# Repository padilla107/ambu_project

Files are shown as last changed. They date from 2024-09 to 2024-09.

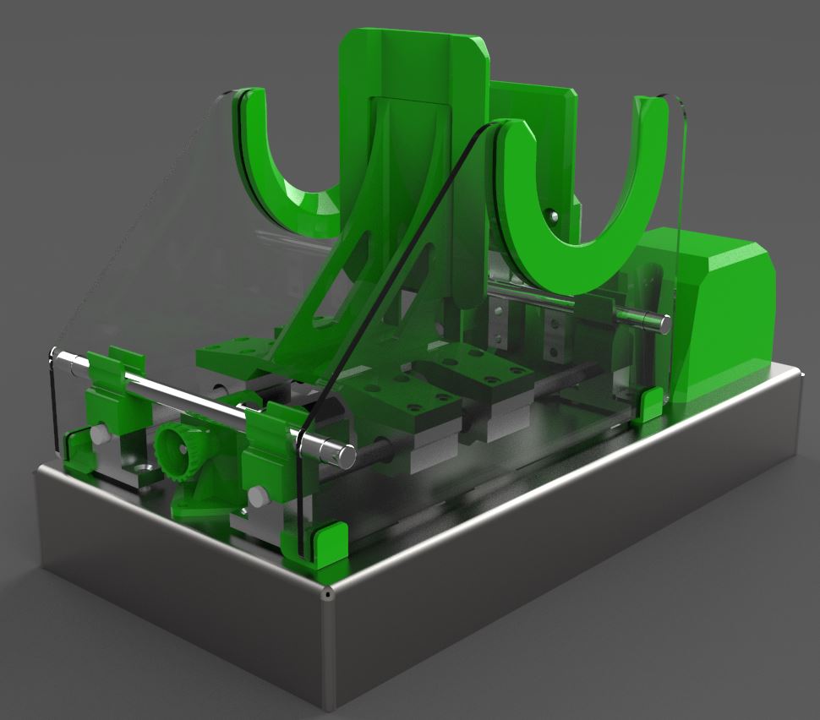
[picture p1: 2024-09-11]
Diseño/Proyección/011.JPG

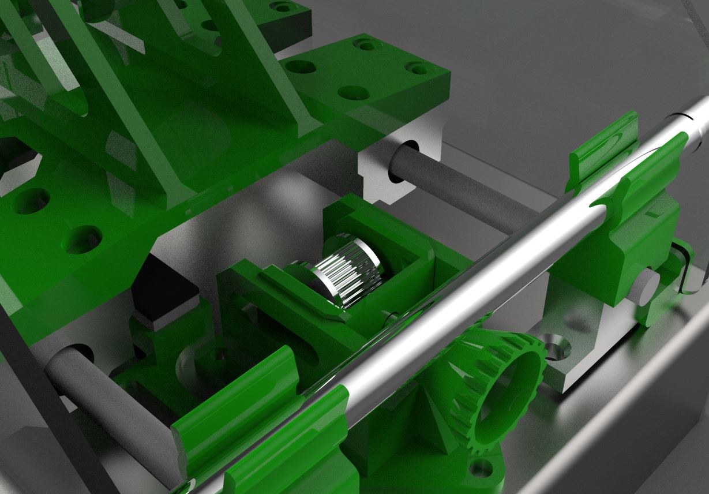
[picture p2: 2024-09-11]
Diseño/Proyección/012.JPG

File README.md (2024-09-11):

# Sistema de Apoyo para la Respiración No Invasivo

## Descripción

Este repositorio contiene los recursos completos para la construcción de un sistema de apoyo respiratorio no invasivo, diseñado para enfrentar la carencia de equipamiento médico en situaciones de emergencia, como la pandemia de COVID-19. El proyecto incluye diseños en 3D, esquemas electrónicos y programación de microcontroladores, con un enfoque en la accesibilidad y el código abierto.

## Recursos Incluidos

- **Diseños 3D**: Archivos en formato STL y OBJ listos para impresión 3D, incluyendo la estructura y componentes mecánicos del sistema.
- **Circuito Esquemático**: Planos electrónicos detallados del dispositivo.
- **Archivos Gerber**: Recursos para la fabricación del PCB, listos para ser enviados a fabricantes de placas de circuito impreso.
- **Código de Programación**: Código fuente para el microcontrolador ESP32, incluyendo la configuración y funcionalidades del sistema.
- **Guía de Fabricación**: Paso a paso detallado para la construcción y montaje del dispositivo, desde la impresión de componentes hasta la programación final.
- **Tesis Completa**: Documento académico que respalda el proyecto, incluyendo la investigación, diseño y desarrollo del sistema.

## Objetivo

Crear una solución replicable y de bajo costo para la ventilación no invasiva, que pueda ser utilizada tanto en entornos hospitalarios como en el hogar.

## Tecnologías Utilizadas

- Microcontroladores ESP32
- Software Autodesk Inventor para diseño mecánico
- Impresoras 3D
- Circuitos PCB con archivos Gerber

## Contribuciones

Este proyecto está diseñado para ser accesible y mejorado por la comunidad. Cualquier contribución para optimizar el diseño, mejorar la programación o adaptar el sistema a nuevas necesidades es bienvenida.

---

# Non-Invasive Breathing Support System

## Description

This repository contains the complete resources for building a non-invasive respiratory support system, designed to address the lack of medical equipment in emergency situations, such as the COVID-19 pandemic. The project includes 3D designs, electronic schematics, and microcontroller programming, with a focus on accessibility and open source.

## Included Resources

- **3D designs**: Files in STL and OBJ format ready for 3D printing, including the structure and mechanical components of the system.
- **Schematic Circuit**: Detailed electronic drawings of the device.
- **Gerber Files**: Resources for PCB manufacturing, ready to be sent to printed circuit board manufacturers.
- **Programming Code**: Source code for the ESP32 microcontroller, including system configuration and functionalities.
- **Manufacturing Guide**: Detailed step by step for the construction and assembly of the device, from component printing to final programming.
- **Complete Thesis**: Academic document that supports the project, including research, system design, and development.

## Aim

Create a low-cost, replicable solution for non-invasive ventilation, that can be used both in hospital environments and at home.

## Technologies Used

- ESP32 Microcontrollers
- Autodesk Inventor software for mechanical design
- 3D printers
- PCB Circuits with Gerber Files

## Contributions

This project is designed to be accessible and enhanced by the community. Any contribution to optimize the design, improve programming, or adapt the system to new needs is welcome.

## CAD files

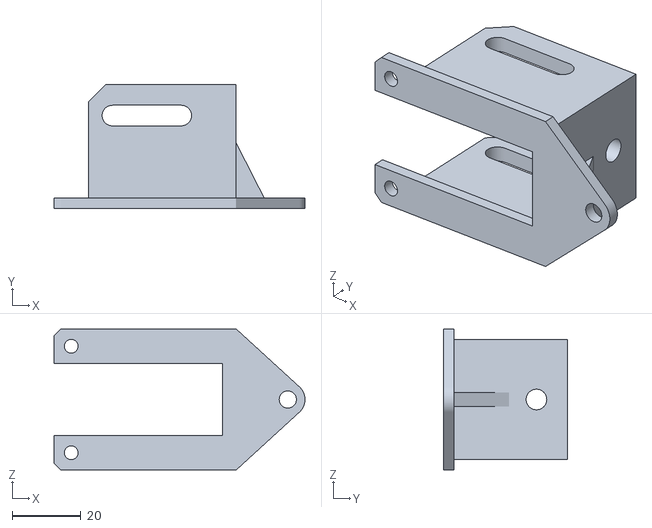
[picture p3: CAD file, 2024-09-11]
Diseño/Impresión 3D/base de tensor.stl
73.0 x 36.0 x 41.0

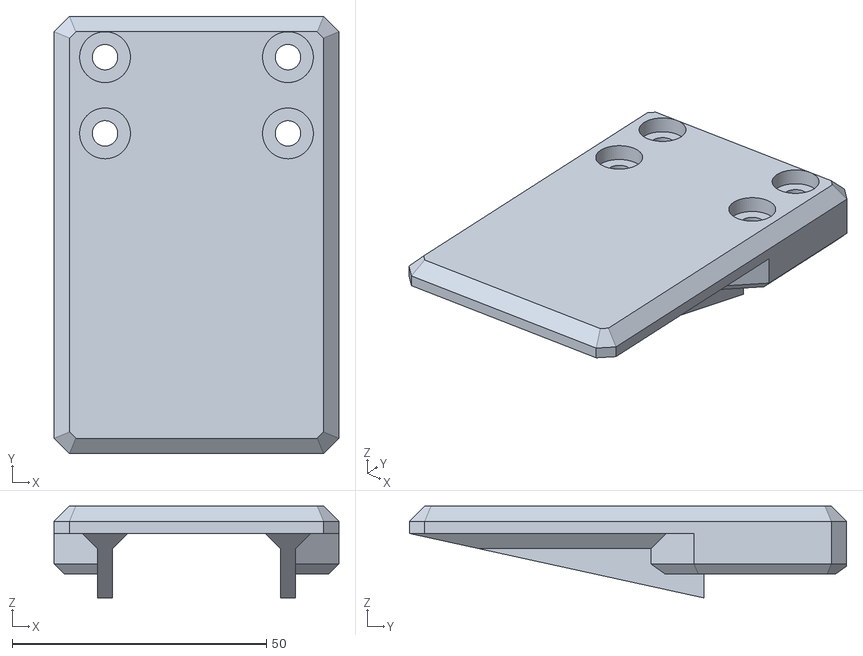
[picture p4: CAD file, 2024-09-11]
Diseño/Impresión 3D/Paleta de celda de carga.stl
56.0 x 86.0 x 18.1

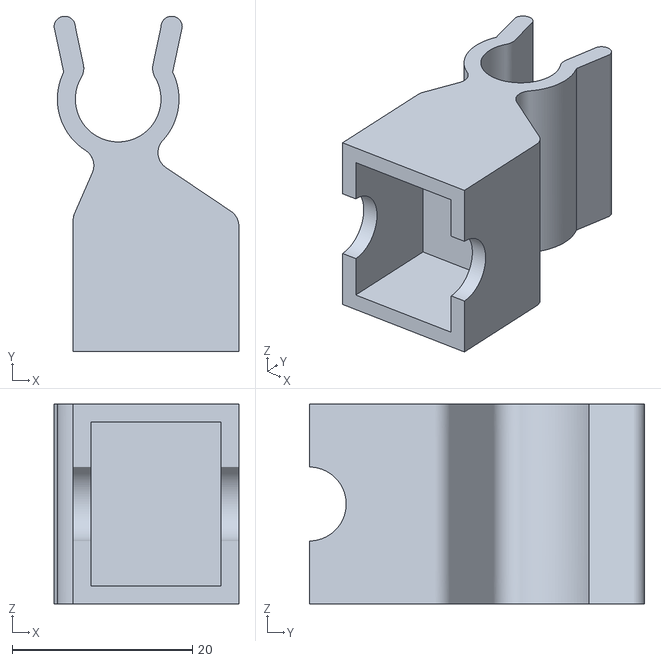
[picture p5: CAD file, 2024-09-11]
Diseño/Impresión 3D/Sujetador tornillo soporte mica delantero.stl
20.5 x 37.2 x 22.2

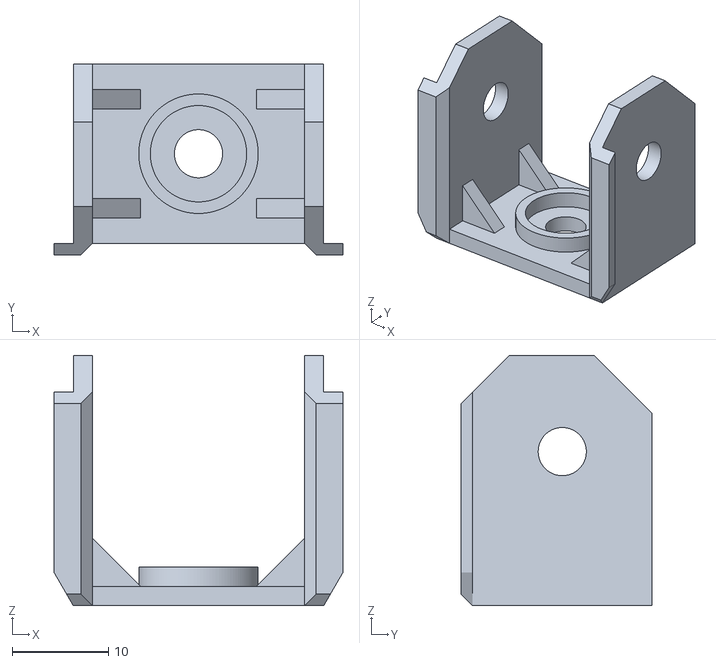
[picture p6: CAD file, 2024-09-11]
Diseño/Impresión 3D/deslizante de tensor.stl
30.0 x 19.8 x 26.0

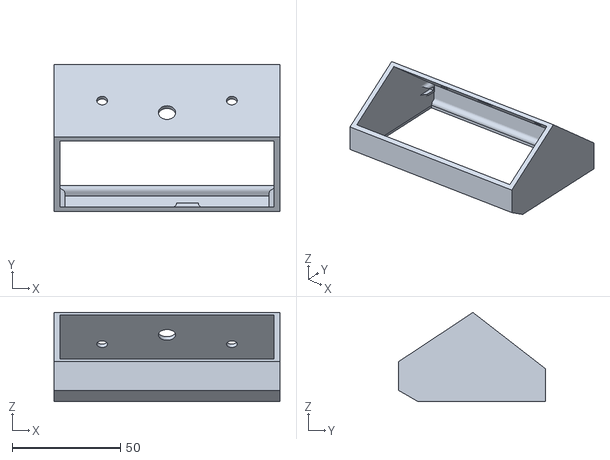
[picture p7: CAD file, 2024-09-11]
Diseño/Impresión 3D/Carcasa LCD.stl
104.5 x 68.0 x 41.2

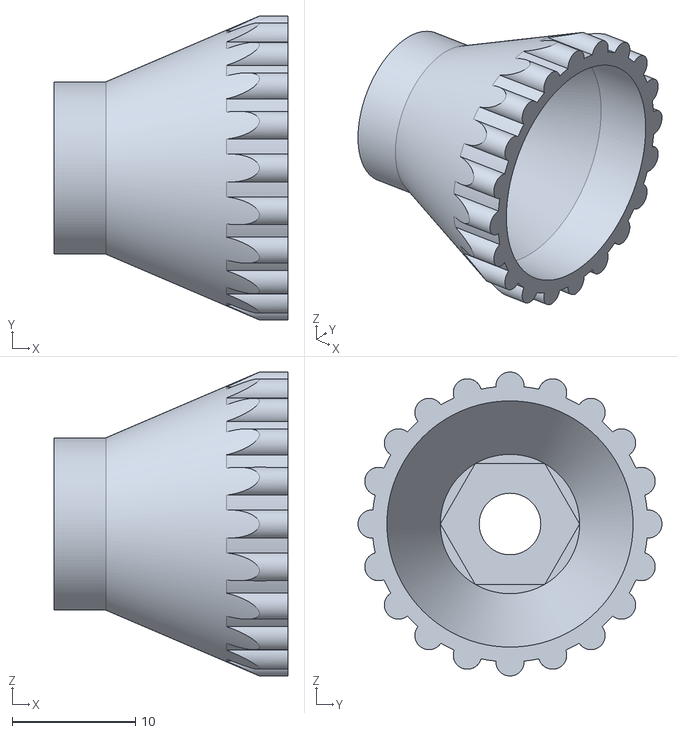
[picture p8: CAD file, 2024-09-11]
Diseño/Impresión 3D/perilla de tensor.stl
19.0 x 24.7 x 24.7

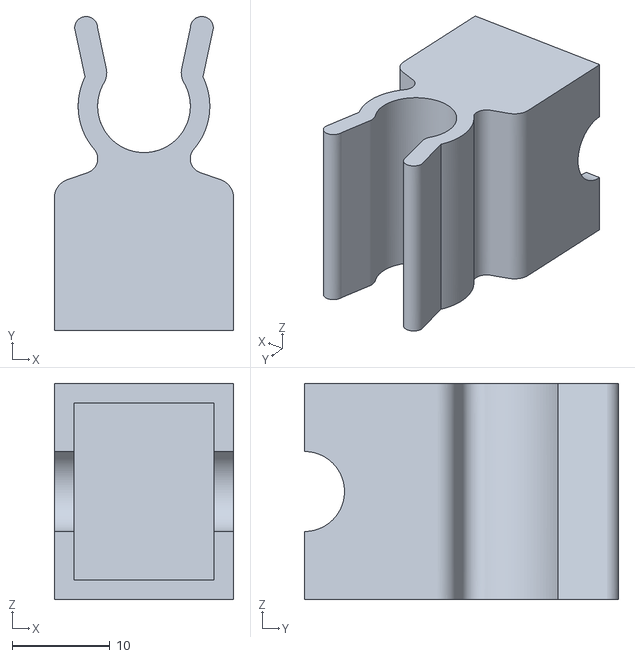
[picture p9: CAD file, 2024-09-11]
Diseño/Impresión 3D/Sujetador tornillo soporte mica trasero.stl
18.4 x 32.2 x 22.2

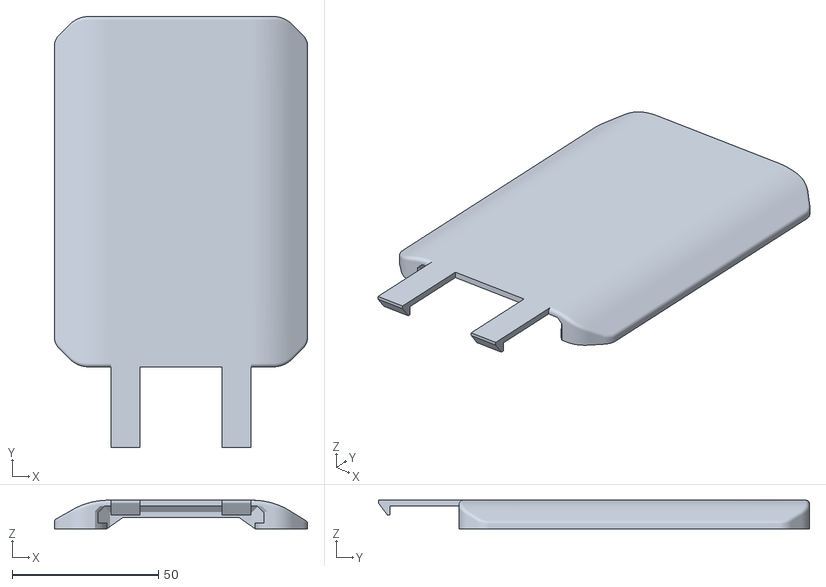
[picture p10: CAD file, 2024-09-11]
Diseño/Impresión 3D/camisa_paleta.stl
86.8 x 147.6 x 9.80

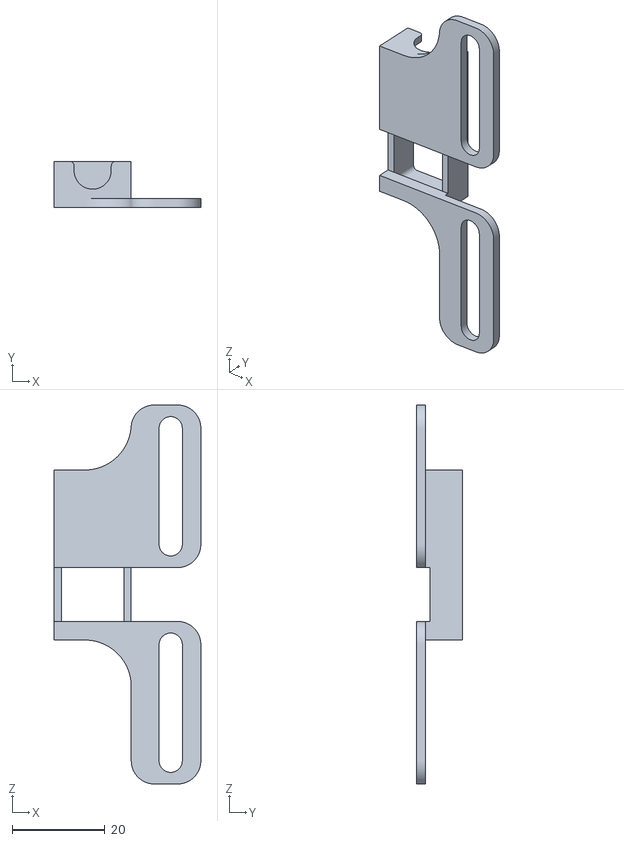
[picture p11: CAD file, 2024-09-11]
Diseño/Impresión 3D/Porta sensor magnetico.stl
31.6 x 10.0 x 81.6

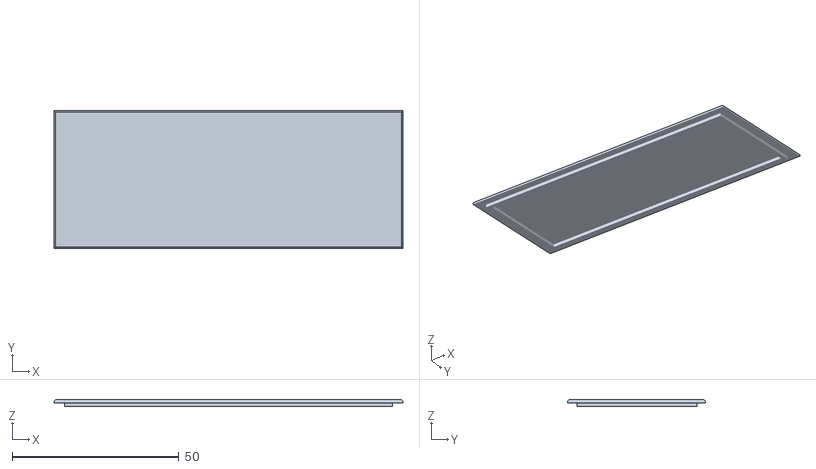
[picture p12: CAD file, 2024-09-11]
Diseño/Impresión 3D/Tapa de carcasa LCD.stl
104.5 x 41.3 x 2.00

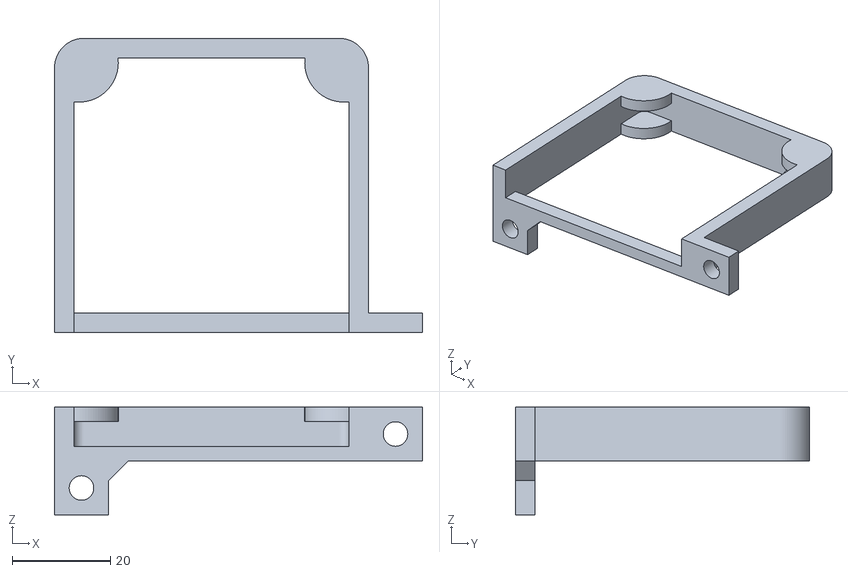
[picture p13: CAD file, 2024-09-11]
Diseño/Impresión 3D/Soporte delantero motor.stl
75.0 x 60.0 x 22.0

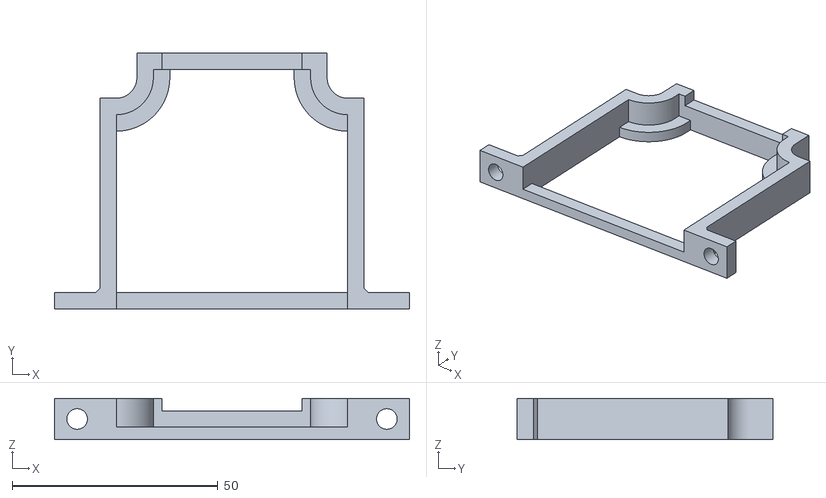
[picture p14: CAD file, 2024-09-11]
Diseño/Impresión 3D/Soporte trasero motor.stl
86.2 x 62.2 x 10.0

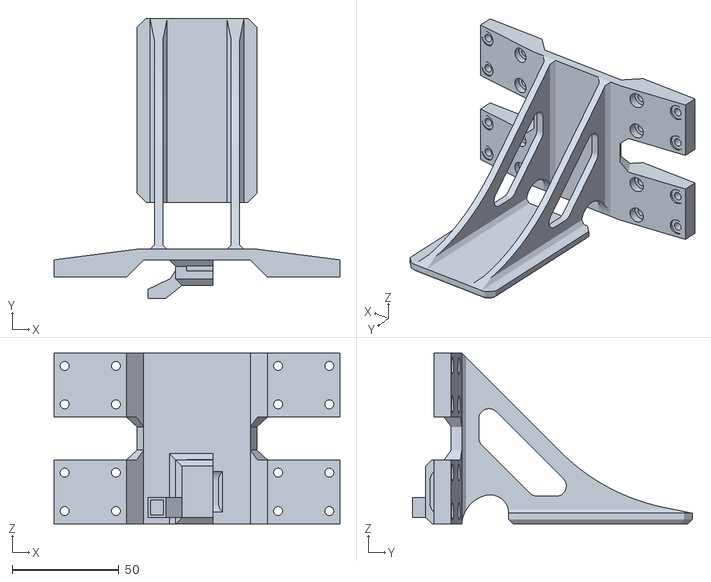
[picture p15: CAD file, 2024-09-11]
Diseño/Impresión 3D/Soporte central.stl
134.0 x 131.0 x 80.0

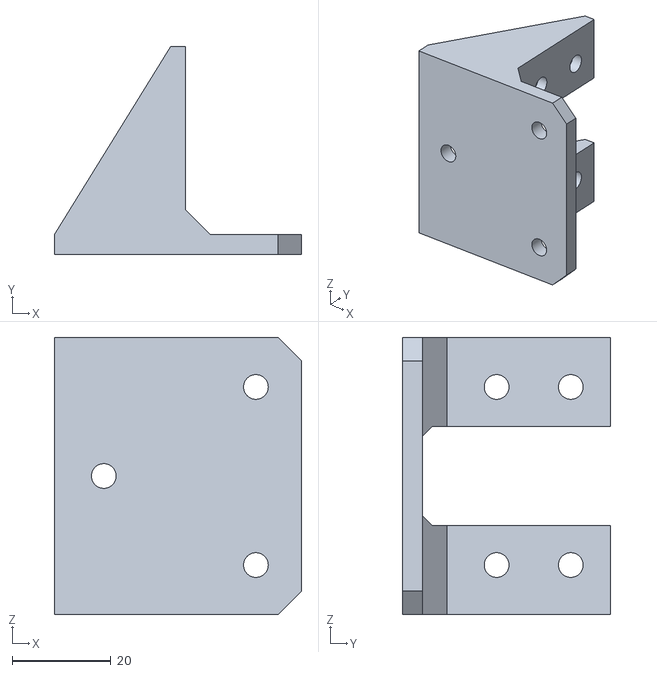
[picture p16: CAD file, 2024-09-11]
Diseño/Impresión 3D/Base de celda de carga.stl
50.0 x 42.0 x 56.0

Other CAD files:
Diseño/Impresión 3D/Sujetador mica derecho.stl
Diseño/Impresión 3D/Cover motor.stl
Diseño/Impresión 3D/Sujetador mica izquierdo.stl

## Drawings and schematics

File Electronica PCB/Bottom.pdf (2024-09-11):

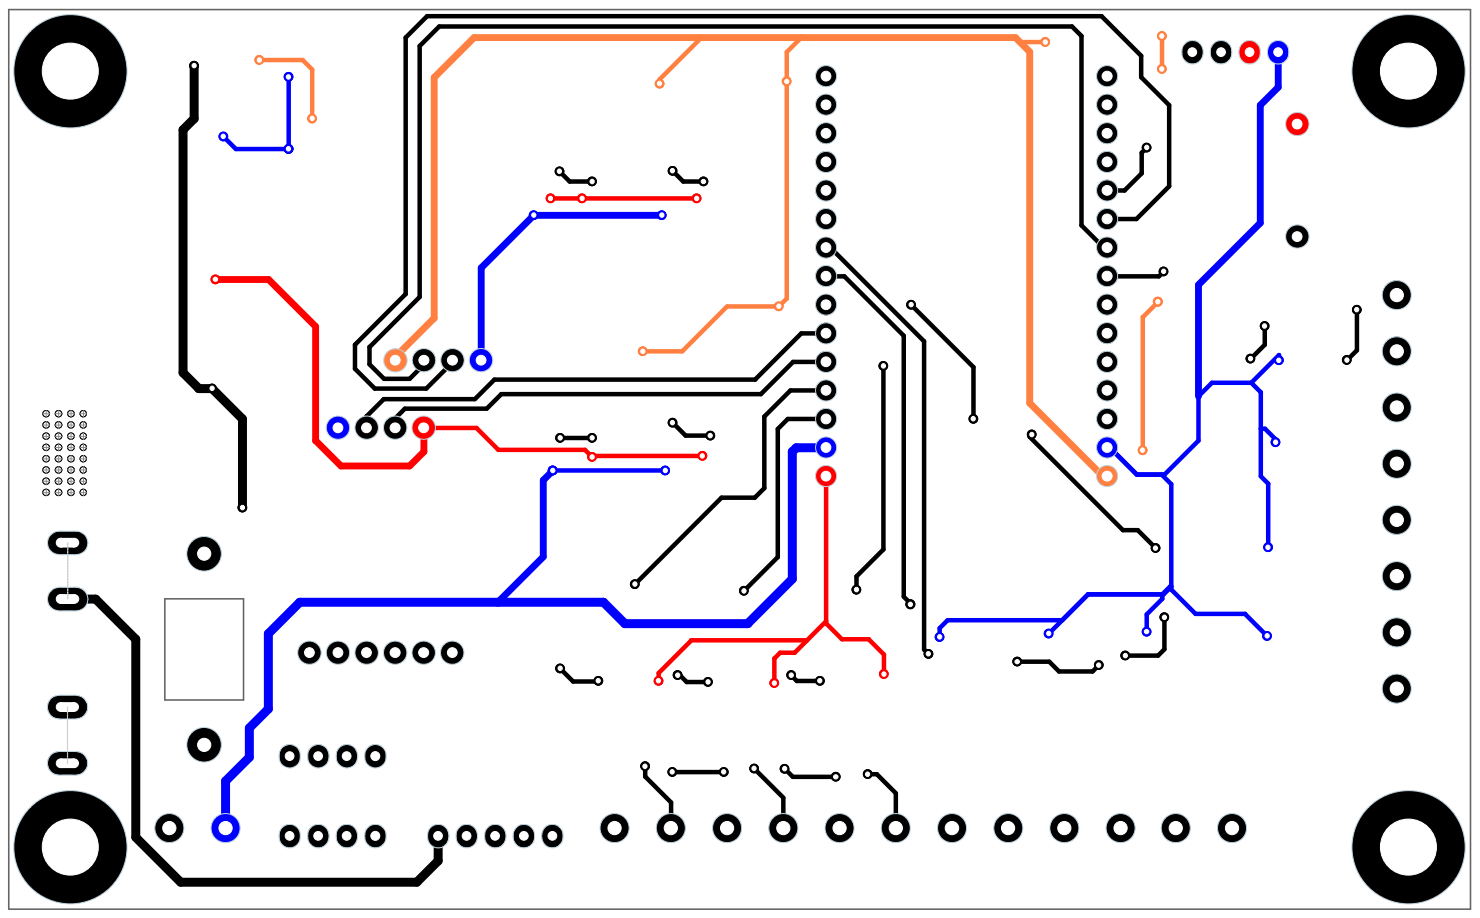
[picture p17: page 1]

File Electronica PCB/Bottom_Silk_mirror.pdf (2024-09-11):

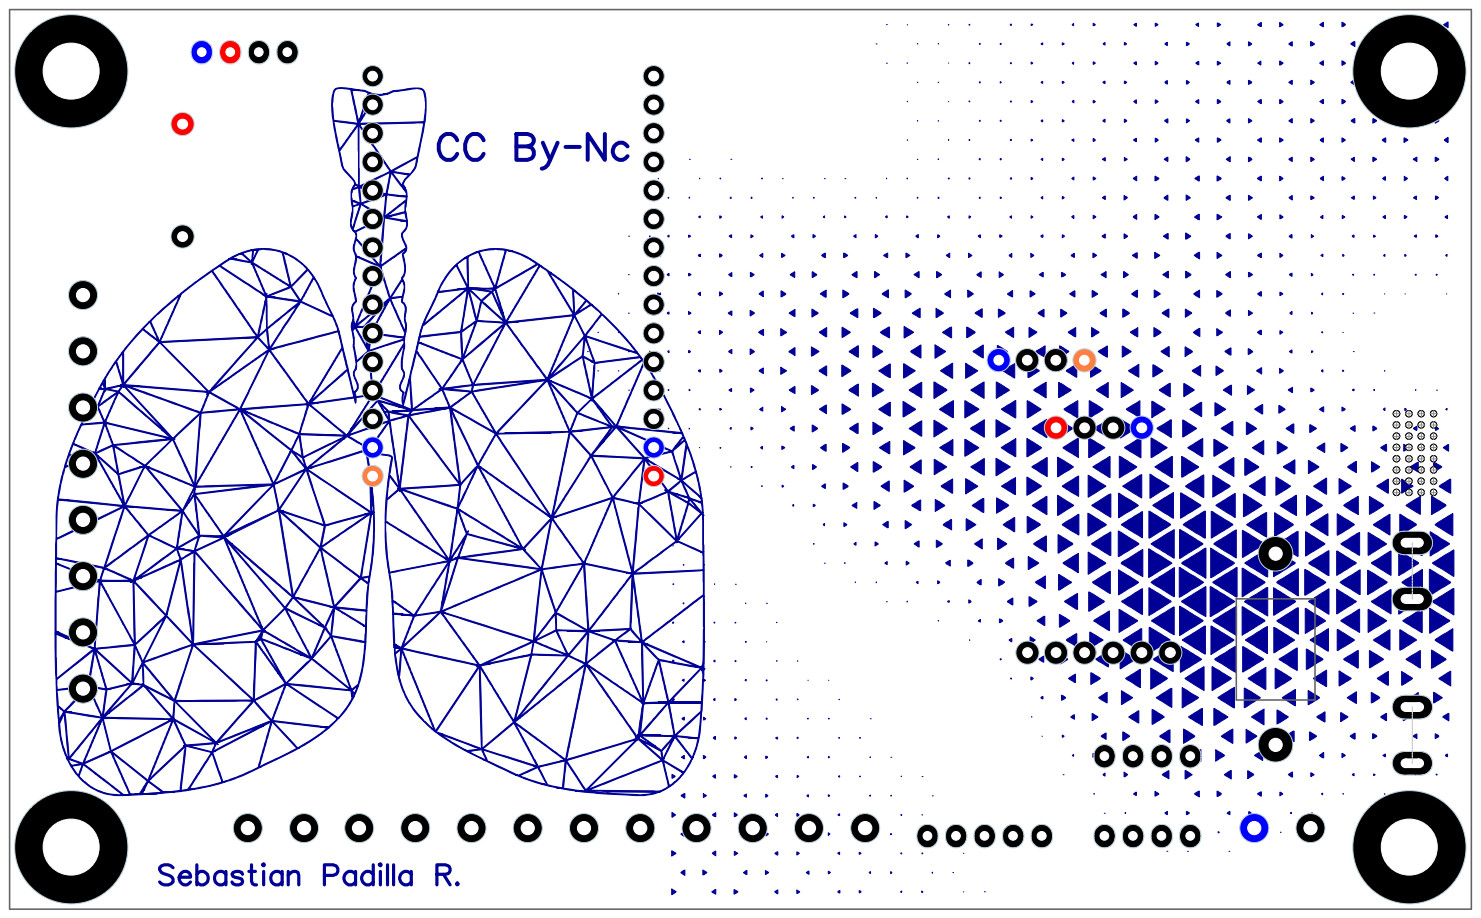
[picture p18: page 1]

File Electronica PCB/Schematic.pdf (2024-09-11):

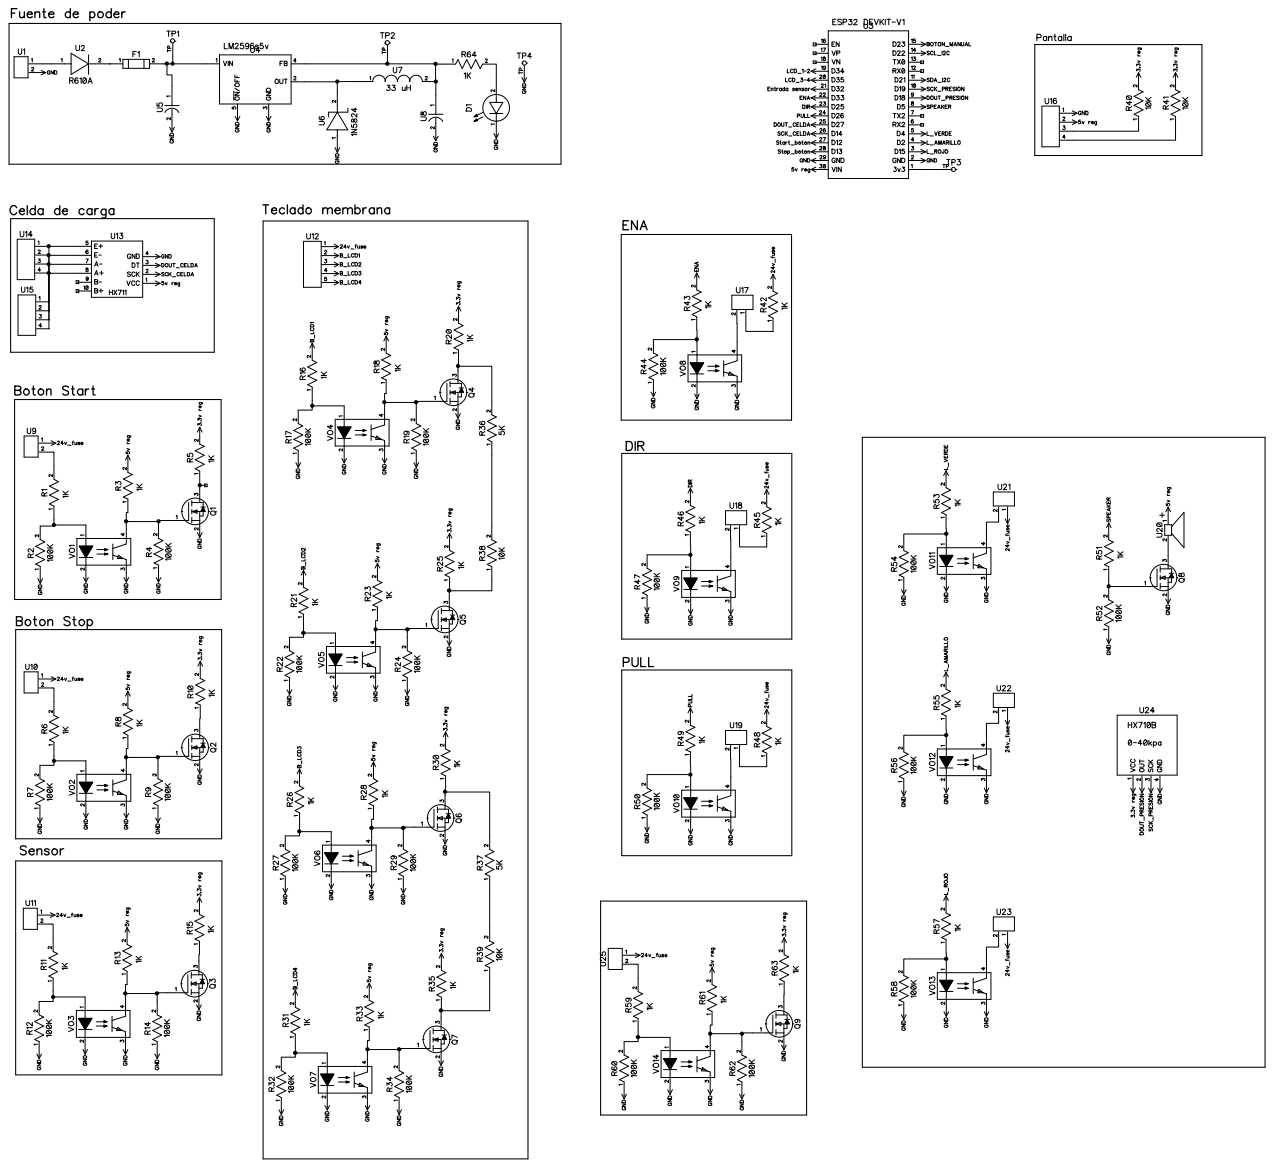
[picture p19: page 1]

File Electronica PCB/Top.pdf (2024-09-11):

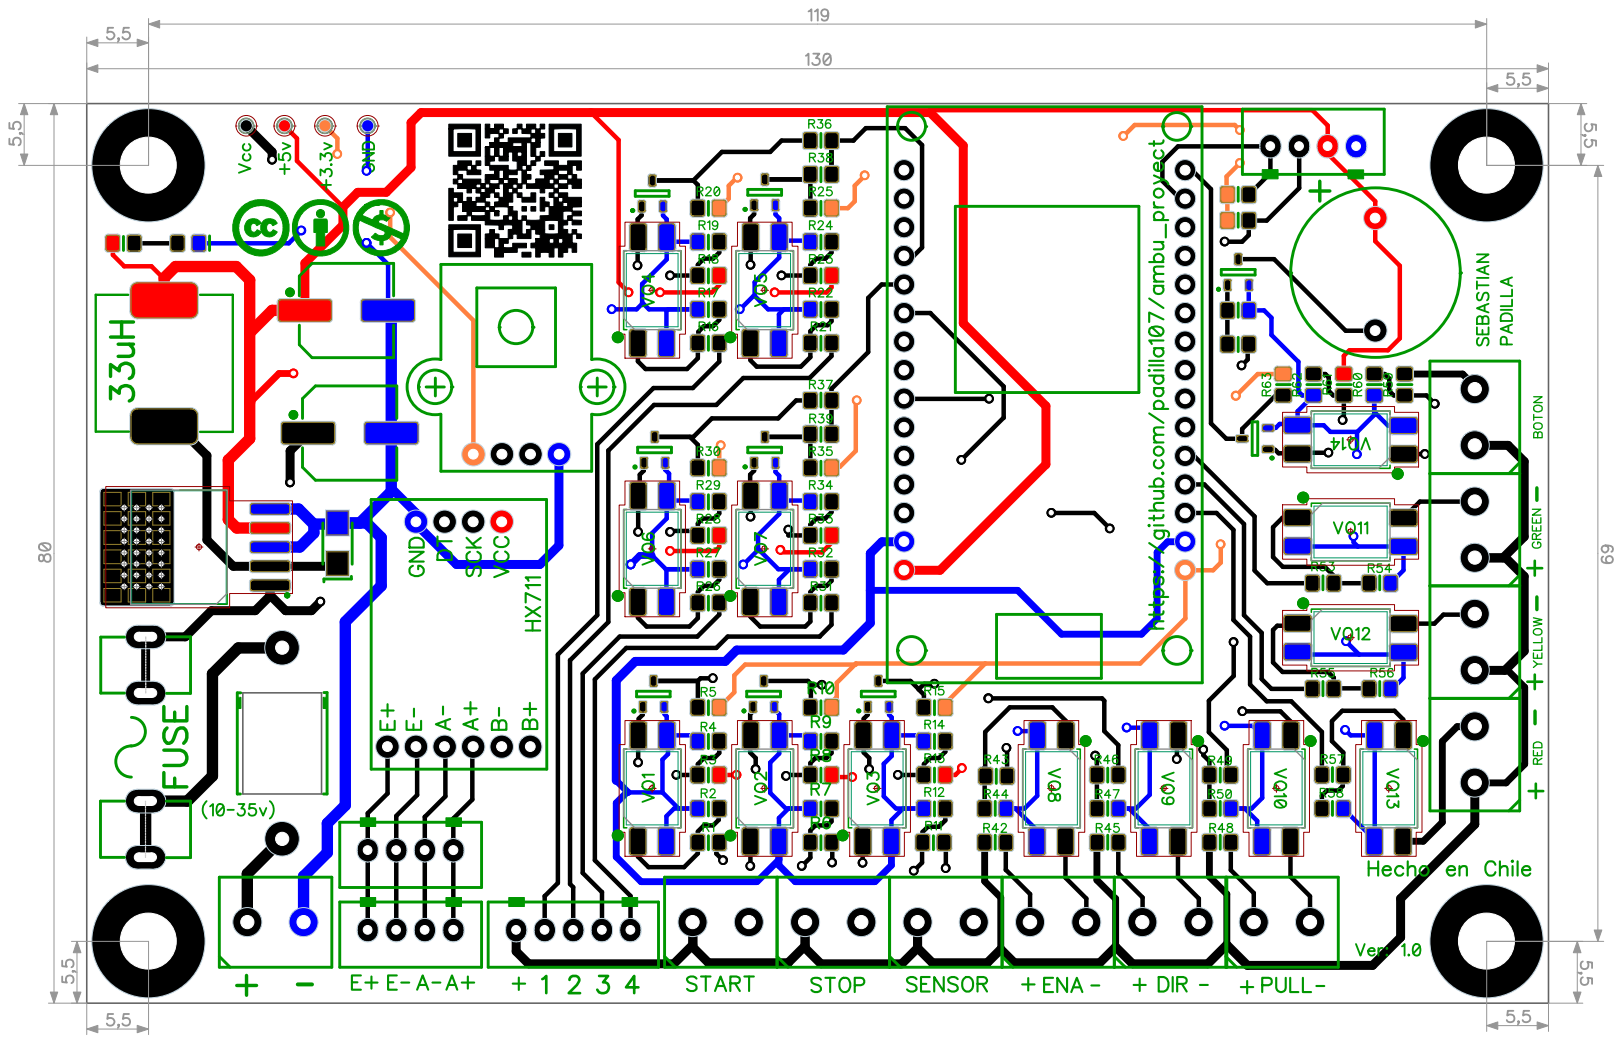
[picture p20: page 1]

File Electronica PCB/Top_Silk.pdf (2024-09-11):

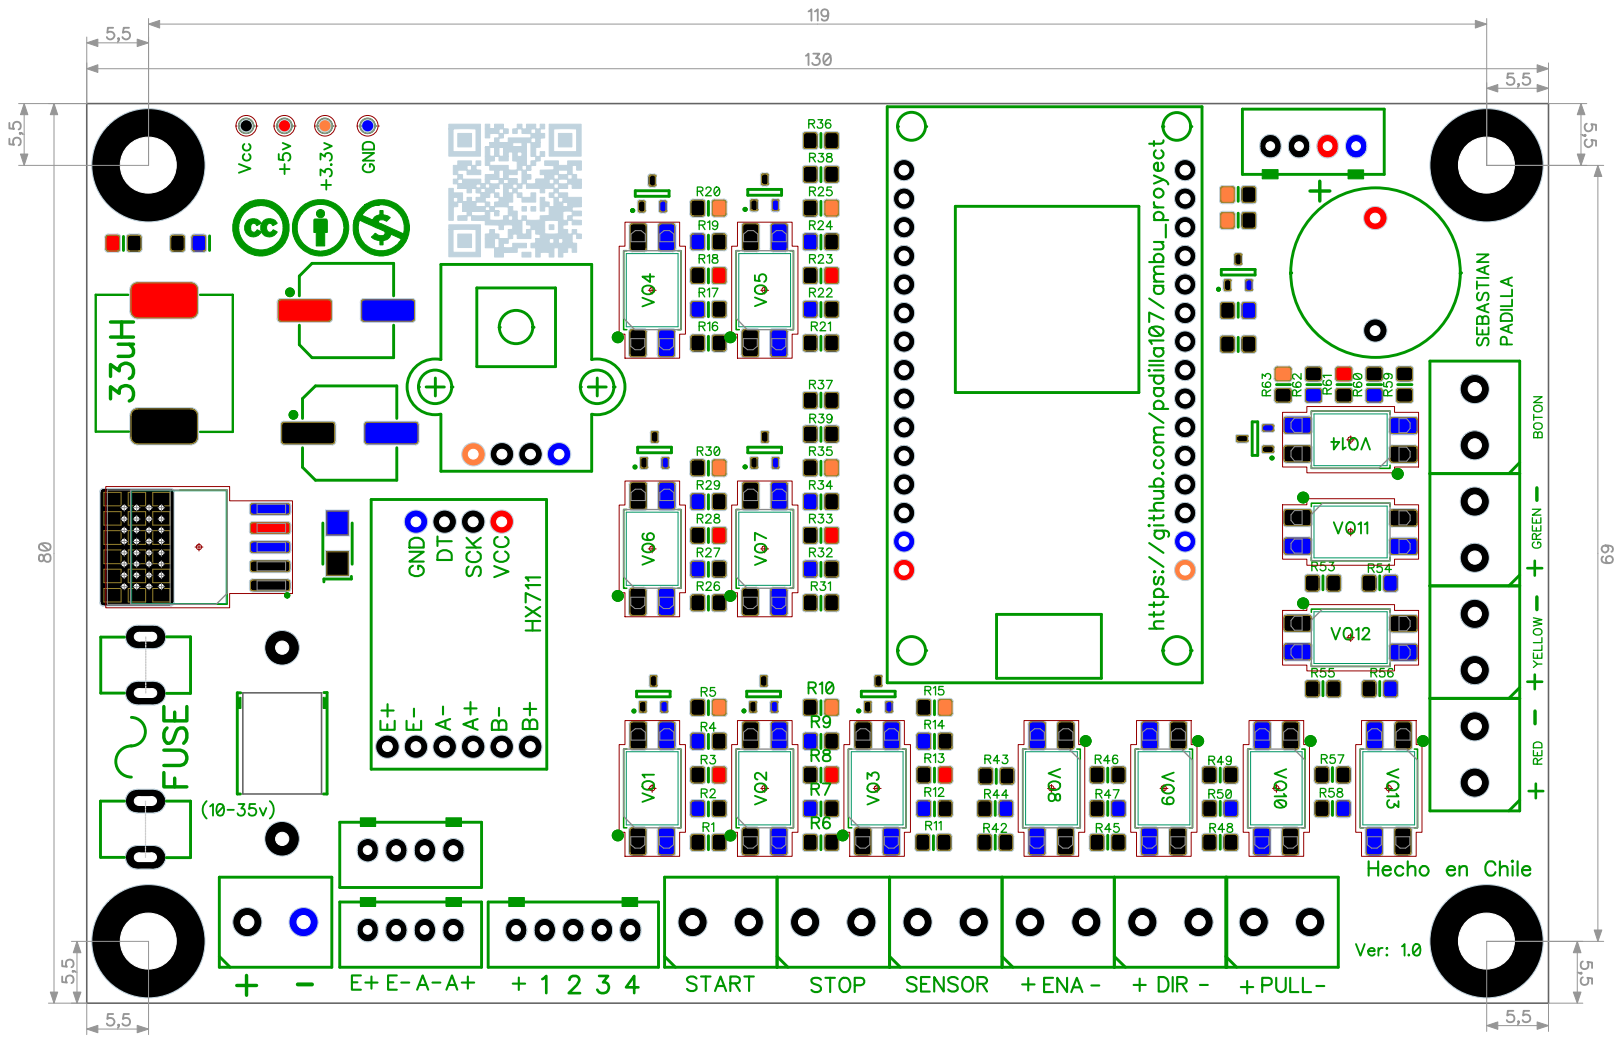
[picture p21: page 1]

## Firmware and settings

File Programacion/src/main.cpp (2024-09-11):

#include <Arduino.h> //14-08-24 002
#include "EEPROM.h"
#include <Wire.h>
#include <LiquidCrystal_I2C.h>
#include <Chrono.h> 
#include <HX711.h>
#include <AccelStepper.h>

LiquidCrystal_I2C lcd(0x27,20,4);

bool prueba_core0=0;

HX711 O_PRESION;
HX711 O_CELDA;

AccelStepper stepper (1,26,25);  // (tipo driver=1 , pull, direccion) pin

const int PRESION_DOUT_PIN = 18;//18
const int PRESION_SCK_PIN = 19;//19

const int CELDA_DOUT_PIN = 27;//27
const int CELDA_SCK_PIN = 14;//14

/////////////////////////////////////////
bool enciende=0;
bool b_inicio=0;
int prueba=0;
int pin_entrada=23;
bool estado_input=0;
///////////////////////////////////////
int Pin_lcd12=34;
int valor_lcd12=0;

int pin_lcd34=35;
int valor_lcd34=0;

float PRESION_CERO=0;
float SENSOR_PRESION=0;
int PRESION=0;
bool trigg=0;
int P_SUMA=0;
float CELDA_CERO=0;
float SENSOR_CELDA=0;
float CELDA=0;
float pos_celda=0;    // dato positivo de celda
int C_SUMA=0;


bool light_on=0;

int n_inspira=1;
bool insp_boton=0;
bool insp_presion=0;
bool insp_tiempo=0;


bool estado_boton_start;
bool estado_boton_stop;
int boton_start=12;                  //pin de entrada
int boton_stop=13;                   //pin de entrda
int luz_amarillo=2;//8             //pin salida
int luz_rojo=15;                     //pin salida
int luz_verde=4;                   //pin salida
int buzzer=5;                      //pin salida
int PinSensor_Mag=32;//11                     /sin usar
bool Sensor_Mag=0;               //sin usar
//int boton_input=0;     
//bool estado_input=0;                     //sin usar

bool actual_1,anterior_1,boton_1;   //estado de boton abajo
bool actual_2,anterior_2,boton_2;   //estado de boton arriba  
bool actual_3,anterior_3,boton_3;   //estado de boton derecha
bool actual_4,anterior_4,boton_4;   //estado de boton izquiera
int pos_f=0;                        //posicion de caracter flecha en el menu
int pag_menu=0;                     //posicion de pagina menu
bool cambio_menu=0;
bool entra_menu=0;                       //  Entrada menu lcd
bool entra_MenuAnterior=0;               // bandera clear lcd
int dato_prueba=50;                     // dato de prueba
////////////////////////////////////      String para concatenar
char conca_d1[30], conca_d2[30], conca_d3[30], conca_d4[30], conca_d5[30], conca_d6[30];
char  conca_d7[30], conca_d8[30], conca_d9[30], conca_d10[30], conca_d11[30], conca_d12[30];
char  conca_d13[30], conca_d14[30], conca_d15[30], conca_d16[30], conca_d17[30], conca_d18[30];

char  conca_A1[30],conca_A2[30],conca_A3[30],conca_A4[30],conca_A1_1[30],conca_A1_2[30];
int conca_linea_A1_1=0;
int conca_linea_A1_2=1;

   
int ant_dato_0;
int dato_0=0;                       // pulsacion de boton start=1 o stop=0  (envia)
int dato_1=10;                        //recorrido 0-100 /                   (10-100)
int dato_2=10;                        //velocidad inspiracion 0-100           (envia)
float dato_3=0;                      //tiempo mantencion                    (0.0 - 5.0)
int dato3_1=0;                       //tiempo mantencion*10(entero)          (envia)
int dato_4=10;                        //velocidad expiracion                  (envia)
float dato_5=0;                      //tiempo reposo                        (0.0 - 5.0)
int dato5_1=0;                       // tiempo reposo (entero)
int dato_6=0;                        // sonido alarma         off/on
int dato_7=0;                        // bip apoyo         off/insp/exp/e+i
int dato_8=0;                        // fuerza            si/no
float dato_9=0.5;                        // Rango de fuerza   0.5-10 kg     (0.5 - 10.0)
int dato_10=0;                       // Accion de F     (det- alarm)
int dato_11=0;                       // Presion inspira (si - no)
int dato_12=-1;                       // Umbral detc.    (10 - 40)
int dato_13=0;                      //  Accion Umb.     (comp-solo)
int dato_14=0;                      //  Presion Max      (si - no)
int dato_15=5;                      // Rango Pmax.      (5-40)
int dato_16=0;                      // Accion Pmax      (det-alarma)
int dato_17=0;                      // Boton          (si - no)
int dato_18=0;                      //  accion boton (detencion/ alarma/insp/auto)
bool alarma=0;                      /// dato de alarma 0 apagada 1 encendido
bool EstadoAmarillo=0;
bool AntAlarm=0;

int menu_preceso=0;
int linea=0;
bool mantenido4=0;
bool mantenido3=0;
bool pulso3=0;
bool pulso4=0;
bool beep_Act=0;
bool beep_Alarm=0;
int  Status=0;
int linea_menu=0;
int linea_alarma=0;
int linea_presion=0;
////////////////////////////          variables de motor
int TRANS_dato_1=0;                        //recorrido 0-100 /                   (10-100)
int TRANS_dato_2=0;                        //velocidad inspiracion 0-100           (envia)
int TRANS_dato3_1=0;                       //tiempo mantencion*10(entero)          (envia)
int TRANS_dato_4=0;                        //velocidad expiracion                  (envia)
int TRANS_dato5_1=0;                       // tiempo reposo (entero)

int home1=0;
int bandera_home=0;
int Calibra1=0;
//int velocidad_home_1=400;
int etapa=0;

int estado_sensor;
int detecta_atras=0;


int home_paso=0;
int funciona=0;
int Longitud=0;                 //map()10-100:200-1000
int Velocidad_Inspira=0;   
int Aceleracion_Inspira=0;

int Aceleracion_Expira=0;     //  
int Velocidad_Expira=0;

int acel_fin_adelante=0;
int acel_inicio_delante=0;
int Rampa_adelante=0;

int pasos_margen=300;
int total_pasos=1200;

int Tiempo_inspira=0;
int Tiempo_reposo=0;

int acel_fin_atras=0;
int acel_inicio_atras=0;
int Rampa_atras=0;

int pulsoUP=10;    /// 10 us


//bool bandera_inspira=0; // bandera de entrada de tiempo
//bool bandera_expira=0; // bandera de entrada de tiempo

///////////////////////////////////////           Temporizadores
Chrono luz;               // backlight  lcd
Chrono timeOut;           // salir del menu
Chrono Tiempo_Beep;       // tiempo de sonido beep
Chrono tiempo_manB4;      // tiempo         
Chrono tiempo1_manB4;
Chrono tiempo_manB3;
Chrono tiempo1_manB3;
Chrono time_alarma;       //  tiempo de alarma
Chrono Refresh_menu;      //  tiempo de refresh LCD

Chrono tiempo_1(Chrono::MICROS);
Chrono tiempo_2(Chrono::MICROS);
Chrono Tiempo_espera;


void alerta(){     
   if(alarma!=AntAlarm){                // inicial de alarma
      EstadoAmarillo=1;
      digitalWrite(luz_amarillo,EstadoAmarillo);
      AntAlarm=alarma;
    }                    
  switch (alarma){   //funcion de luz y sonido alternado
    case 0:
      EstadoAmarillo=0;
      digitalWrite(luz_amarillo,EstadoAmarillo);     //apagado de luz
     time_alarma.restart();                      //reset tiempo de luz
     time_alarma.stop();                         //stop tiempo de luz 
    break;
    case 1:
      time_alarma.resume();
      if (time_alarma.hasPassed(250)){
        EstadoAmarillo=!EstadoAmarillo;  
        if((EstadoAmarillo)&&(dato_6)){
          beep_Alarm=1;
        }                          // si es distinto
        digitalWrite(luz_amarillo,EstadoAmarillo);  //  
        dato_prueba=1;
        time_alarma.restart();                    // reset tiempo alarma
      }                    
    break;
  }
}

void beep_respiracion(){
  if((beep_Act)||(beep_Alarm)){
    Tiempo_Beep.resume();
    digitalWrite(buzzer,HIGH);
   
  }
  if (Tiempo_Beep.hasPassed(50)){
    beep_Act=0;
    beep_Alarm=0;
    digitalWrite(buzzer,LOW);
    Tiempo_Beep.restart();
    Tiempo_Beep.stop();
  }


} //fin de void beep

void inicio (){
  if(enciende==0){
    dato_0=EEPROM.readInt(0);
    dato_1=EEPROM.readInt(10);
    dato_2=EEPROM.readInt(20);
    dato_3=EEPROM.readFloat(30);
    dato_4=EEPROM.readInt(40);
    dato_5=EEPROM.readFloat(50);
    dato_6=EEPROM.readInt(60);
    dato_7=EEPROM.readInt(70);
    dato_8=EEPROM.readInt(80);
    dato_9=EEPROM.readFloat(90);
    dato_10=EEPROM.readInt(100);
    dato_11=EEPROM.readInt(110);
    dato_12=EEPROM.readInt(120);
    dato_13=EEPROM.readInt(130);
    dato_14=EEPROM.readInt(140);
    dato_15=EEPROM.readInt(150);
    dato_16=EEPROM.readInt(160);
    dato_17=EEPROM.readInt(170);
    dato_18=EEPROM.readInt(180);

    dato3_1=int(((dato_3)*10)+0.4);
    dato5_1=int(((dato_5)*10)+0.4);

    if(dato_0==1){
        b_inicio=1;     
      }
    enciende=1;
  }
    
}
void Input(){
  estado_boton_start=digitalRead(boton_start);
  estado_boton_stop=digitalRead(boton_stop);
  estado_sensor=digitalRead(PinSensor_Mag);
}
void sensor_celda(){

  
  CELDA=(((O_CELDA.read())-(CELDA_CERO))/97250);   // PRESION 115600
  
  if(dato_8){ // activacioon sensor fuerza
    if((CELDA>=dato_9)&&(dato_0)){
      switch (dato_10)  // detencion o aviso
      {
      case 0:
          alarma=1;
          etapa=0;
          linea_alarma=3;
          stepper.setCurrentPosition(0);
        break;

      case 1:
           alarma=1;
           linea_alarma=3;

        break;
      }
    }
  }
}
 void sensor_presion(){
  PRESION=(((O_PRESION.read())-(PRESION_CERO))/64285); //  (cmH2O o mbar) 
  if(dato_14){
    if(PRESION>=dato_15){
      switch  (dato_16)
      {
        case 0:
          alarma=1;
          etapa=0;
          linea_alarma=4;
          stepper.setCurrentPosition(0);
        break;
        case 1:
          alarma=1;
          linea_alarma=4;
        break;
      }
    }
  }
if(dato_11){
  if(PRESION<=dato_12){
    trigg=1;
  }
  else{
    trigg=0;
  } 
 }
}



void pin_input(){
  estado_input=digitalRead(pin_entrada);
  if((dato_17)&&(estado_input)){
      switch  (dato_18)
      {
        case 0:
          alarma=1;
          etapa=0;
          linea_alarma=5;
          stepper.setCurrentPosition(0);
        break;
        case 1:
          alarma=1;
          linea_alarma=5;
        break;
      }
    
  }
}
void proceso(){
  
  if(((estado_boton_start)||(b_inicio==1)) && (etapa==0)){
     etapa=1;
     b_inicio=0;
     //Tiempo_espera.start();
  }
  if((estado_boton_start) && ((linea_alarma>=3))){   /// reset de alarmas con start
    alarma=0;
    linea_alarma=0;
  }
  if(estado_boton_stop){
    etapa=0;
    alarma=0;
    linea_alarma=0;
    Tiempo_espera.restart();
    Tiempo_espera.stop();
    stepper.setCurrentPosition(0);
    stepper.disableOutputs ();
  }
  if(etapa==0){
    digitalWrite(luz_rojo,1);
    digitalWrite(luz_verde,0);
  }
  if(etapa!=0){
    digitalWrite(luz_rojo,0);
    digitalWrite(luz_verde,1);
  }
  if((home1==12)||home1==32){        

    TRANS_dato_1=dato_1;               //recorrido 10-100 /          
    TRANS_dato_2= dato_2;              //velocidad inspiracion 0-100 
    TRANS_dato3_1=dato3_1;            //tiempo mantencion*10(entero)
    TRANS_dato_4= dato_4;             //velocidad expiracion        
    TRANS_dato5_1=dato5_1;            // tiempo reposo (entero)
    Longitud=map(TRANS_dato_1,10,100,200,1000);      //pasos longitud
    Tiempo_inspira=map(TRANS_dato3_1,0,50,1,5000);      // TIEMPO INSPIRA (ms)
    Tiempo_reposo=map(TRANS_dato5_1,0,50,1,5000);
  }
  
}

void teclado(){
  valor_lcd12=analogRead(Pin_lcd12); //  analogico para boton 1,2
  if((valor_lcd12 > 850)&&(valor_lcd12  <1500)) {actual_2=1;  } else  {actual_2=0;}
  if((valor_lcd12 >1500)&&(valor_lcd12  <3500)) {actual_1=1;  } else  {actual_1=0;}
  valor_lcd34=analogRead(pin_lcd34);
  if((valor_lcd34 > 850)&&(valor_lcd34  <1500)) { actual_4=1; } else  {actual_4=0;}
  if((valor_lcd34 >1500)&&(valor_lcd34  <3500)) { actual_3=1; } else  {actual_3=0;}
  //boton 3 mantenido
  if(actual_3==1){            //codigo de mantencion de boton
    tiempo_manB3.resume();
    tiempo1_manB3.resume();
  }
  if(tiempo_manB3.elapsed()>500){
    mantenido3=1;
  }
  if(actual_3==0){
    tiempo_manB3.restart();
    tiempo_manB3.stop();
    tiempo1_manB3.restart();
    tiempo1_manB3.stop();
    pulso3=0;
    mantenido3=0;
  }
  // boton 3 pulsos
  if(mantenido3==1){
    if(tiempo1_manB3.hasPassed(50)){
      pulso3=1;
      cambio_menu=1;
      tiempo1_manB3.restart();
    }
  }
  //boton 4 mantenido
  if(actual_4==1){
    tiempo_manB4.resume();
    tiempo1_manB4.resume();
  }
  if(tiempo_manB4.elapsed()>500){
    mantenido4=1;
  }
  if(actual_4==0){
    tiempo_manB4.restart();
    tiempo_manB4.stop();
    tiempo1_manB4.restart();
    tiempo1_manB4.stop();
    pulso4=0;
    mantenido4=0;
  }
  if(mantenido4==1){
    if(tiempo1_manB4.hasPassed(50)){
      pulso4=1;
      cambio_menu=1;
      tiempo1_manB4.restart();
    }
  }
  switch (actual_1) { // lach boton 1
    case 0:
      switch (anterior_1)
      {
        case 0: boton_1=LOW;  anterior_1=LOW; break;
        case 1: boton_1=LOW;  anterior_1=LOW; break;
      }
    break;
    case 1:
      switch (anterior_1)
      {
        case 0: boton_1=HIGH; cambio_menu=1;  anterior_1=HIGH;  break;
        case 1: boton_1=LOW;  anterior_1=HIGH;  break;  
      }  
    break;
  }
  switch (actual_2){ // lach boton 2
    case 0:
      switch (anterior_2)
      {
        case 0: boton_2=LOW;  anterior_2=LOW; break;
        case 1: boton_2=LOW;  anterior_2=LOW; break;
      }
    break;
    case 1:
      switch (anterior_2)
      {
        case 0: boton_2=HIGH; cambio_menu=1;  anterior_2=HIGH;  break;
        case 1: boton_2=LOW;  anterior_2=HIGH;  break;  
      }  
    break;
  }
  switch (actual_3){ // lach boton 3
    case 0:
      switch (anterior_3)
      {
        case 0: boton_3=LOW;  anterior_3=LOW; break;
        case 1: boton_3=LOW;  anterior_3=LOW; break;
      }
    break;
    case 1:
      switch (anterior_3)
      {
        case 0: boton_3=HIGH; cambio_menu=1;  anterior_3=HIGH;  break;
        case 1: boton_3=LOW;  anterior_3=HIGH;  break;  
      }  
    break;
  }

  switch (actual_4){  // lach boton 3
    case 0:
      switch (anterior_4)
      {
        case 0: boton_4=LOW;  anterior_4=LOW; break;
        case 1: boton_4=LOW;  anterior_4=LOW; break;
      }
    break;
    case 1:
      switch (anterior_4)
      {
        case 0: boton_4=HIGH; cambio_menu=1;  anterior_4=HIGH;  break;
        case 1: boton_4=LOW;  anterior_4=HIGH;  break;  
      }  
    break;
  }
}

void light(){// tempo luz fondo
  if (actual_1||actual_2||actual_3||actual_4||mantenido3||mantenido4||(linea_alarma!=0)){
    luz.restart();                        
    timeOut.restart();   
    //lcd.setBacklight(1);
    if(light_on==0){                    // una vez
      light_on=1;
      lcd.setBacklight(1);              //ENCENDER LUZ}         
    }
  }
  if (luz.elapsed() > 120000){ //15
    luz.restart();
    luz.stop();
    pos_f=0;
    pag_menu=0;
    lcd.setBacklight(0);
  }
}
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
void loop(){
  inicio();
  Input(); 
  proceso();
  teclado();
  menu_logica(); 

  switch (etapa){
    case 0:

        stepper.setCurrentPosition(0);
        stepper.disableOutputs ();
        Status=0;
    break;
    case 1:
        alarma=1;
        Status=1;
        Tiempo_espera.restart();
        etapa=2;
    break;
    case 2:  // tiempo de espera para iniciar calibracion
      if(Tiempo_espera.hasPassed(1000)){
        Tiempo_espera.restart();
        Tiempo_espera.stop();
        etapa=3;
      }
    break;

    case 3:
        stepper.enableOutputs();
        stepper.setAcceleration(2000);
        stepper.setMaxSpeed(4200);
        stepper.moveTo(100);
       // 
        etapa=4;
    break;

    case 4:
        if(stepper.currentPosition() >=100 ){ //no encontro sensor ida
        stepper.setCurrentPosition(0);
        Tiempo_espera.start();
        etapa=5;
        }
    break;
    case 5:     /// tiempo de espera para buscar home hacia atras
      if(Tiempo_espera.hasPassed(200)){
        Tiempo_espera.restart();
        Tiempo_espera.stop();
        etapa=6;
      }
    break;

    case 6:

       //stepper.enableOutputs();
        stepper.setMaxSpeed(1000);   // velocidad  hacia atras 
        stepper.moveTo(-1000);
        etapa=7;
    break;

    case 7:
    if(stepper.currentPosition() <= -1000 ){   // no encontro sensor vuelta
      stepper.setCurrentPosition(0);
      etapa=0;
      linea_alarma=1;
    }
    break;
    case 8:
      //stepper.stop();
      stepper.setMaxSpeed(200);
      stepper.moveTo(-150);
      etapa=9;
    break;


    case 9:
      if(stepper.currentPosition() == (-150) ){ // sensor no acciona
        stepper.setCurrentPosition(0);
        etapa=0;
        linea_alarma=2;
      }
      if(estado_sensor==0){                         //posicion home
        stepper.setCurrentPosition(0);
        Tiempo_espera.restart();
        etapa=10;
      }
    break;

    case 10:
    if(Tiempo_espera.hasPassed(1000)){           // tiempo de espera despues de calibracion 
        Tiempo_espera.restart();
        Tiempo_espera.stop();
        alarma=0;
        //stepper.disableOutputs();
        etapa=11;
        Status=2;
      }
    break;
    case 11:                    //// calculos iniciales
    
    TRANS_dato_1=dato_1;               //recorrido 10-100 /          
    TRANS_dato_2= dato_2;              //velocidad inspiracion 0-100 
    TRANS_dato3_1=dato3_1;            //tiempo mantencion*10(entero)
    TRANS_dato_4= dato_4;             //velocidad expiracion        
    TRANS_dato5_1=dato5_1;            // tiempo reposo (entero)

    Longitud=map(TRANS_dato_1,10,500,200,1000);
    
    Velocidad_Inspira=map(TRANS_dato_2,10,100,1500,4000);
    Aceleracion_Inspira=map(Velocidad_Inspira,1500,4000,1500,18000);
    
    Tiempo_inspira=map(TRANS_dato3_1,0,50,1,5000);      // TIEMPO INSPIRA (ms)
   
    Velocidad_Expira=map(TRANS_dato_4,10,100,1500,4000);
    Aceleracion_Expira=map(Velocidad_Expira,1500,4000,1500,18000);

    Tiempo_reposo=map(TRANS_dato5_1,0,50,1,5000);
    //CELDA_CERO=(O_CELDA.read());
    etapa=12;
    break;
    case 12:                            ///        Movimiento INSPIRACION
    stepper.setMaxSpeed(Velocidad_Inspira);
    stepper.moveTo(Longitud);
    stepper.setAcceleration(Aceleracion_Inspira);
    etapa=13;
    break;
    case 13:
      if(stepper.currentPosition() == Longitud ){
        stepper.setCurrentPosition(0);
        Tiempo_espera.start();
        etapa=14;
      } //no encontro sensor ida
    break;
    case 14:
    if(Tiempo_espera.hasPassed(Tiempo_inspira)){        // Tiempo INSPIRACION
        Tiempo_espera.restart();
        Tiempo_espera.stop();
       // stepper.disableOutputs ();
        etapa=15;
      }
    break;
    case 15:

    stepper.setMaxSpeed(Velocidad_Expira);
    stepper.moveTo(-Longitud +30);                    // margen sensor
    stepper.setAcceleration(Aceleracion_Expira);
    etapa=16;

    break;
    case 16:
    if(stepper.currentPosition() == (-Longitud +30) ){ // sensor no encontrado
      stepper.setCurrentPosition(0);
      etapa=0;
      alarma=1;
      linea_alarma=1;

    }
    if(estado_sensor){
      //stepper.setCurrentPosition(0);
      stepper.stop();
      stepper.setMaxSpeed(500);
      stepper.moveTo(-Longitud-50);
      etapa=17;  
        
    }
    break;
    case 17:
      if(stepper.currentPosition() == (-Longitud-50) ){ // sensor no acciona
        stepper.setCurrentPosition(0);
        etapa=0;
        alarma=1;
        
        linea_alarma=2;
      }
     if(estado_sensor==0){                         //posicion home Expiracion
        stepper.setCurrentPosition(0);
        Tiempo_espera.start();
        etapa=18;
      }
    break;
    case 18:
      switch (n_inspira)
      {
        case 1: 
            if(Tiempo_espera.hasPassed(Tiempo_reposo)){        // Tiempo INSPIRACION
            Tiempo_espera.restart();
            Tiempo_espera.stop();
            etapa=11;
          }
        break;
        case 2:
          if(trigg==HIGH){
            Tiempo_espera.restart();
            Tiempo_espera.stop();
            //trigg=0;
            etapa=11;
          }
        break;
        case 3:
          if((Tiempo_espera.hasPassed(Tiempo_reposo))||(trigg)){        // Tiempo INSPIRACION
            Tiempo_espera.restart();
            Tiempo_espera.stop();
            //trigg=0;
            etapa=11;
          }

        break;
        case 4:
          if(estado_input){
             Tiempo_espera.restart();
            Tiempo_espera.stop();
            //trigg=0;
            etapa=11;
          }
        break;
        case 5:
          if((Tiempo_espera.hasPassed(Tiempo_reposo))||(estado_input)){        // Tiempo INSPIRACION
            Tiempo_espera.restart();
            Tiempo_espera.stop();
            //trigg=0;
            etapa=11;
          }
        break;
        case 6:
          if((trigg)||(estado_input)){
            Tiempo_espera.restart();
            Tiempo_espera.stop();
            //trigg=0;
            etapa=11;
          }
        break;
        case 7:
          if((Tiempo_espera.hasPassed(Tiempo_reposo))||(estado_input)||(trigg)){        // Tiempo INSPIRACION
            Tiempo_espera.restart();
            Tiempo_espera.stop();
            //trigg=0;
            etapa=11;
          }
        break;
      }
    break;
  }  

  //////////////  boton
  if(dato_17){
    if(dato_18>=2){
      insp_boton=1;
    }
    else{insp_boton=0;}
  }
  else{insp_boton=0;}
  ////////////    presion
  if(dato_11){
    if(dato_13>=0){
      insp_presion=1;
    }
    else{insp_presion=0;}
    ///insp_presion=0;
  }
  else{insp_presion=0;}
  ///////////    tiempo
  if((insp_presion==0)&&(insp_boton==0)){
    insp_tiempo=1;
  }
  else if((insp_presion)&&(dato_13)){
    insp_tiempo=1;
  }
  else if((insp_boton)&&(dato_18==3)){
    insp_tiempo=1;
  }
  else{
    insp_tiempo=0;
  }
  n_inspira=insp_boton*4+insp_presion*2+insp_tiempo; 

  if(estado_sensor && (etapa==4 ||etapa==7) ){
    stepper.setCurrentPosition(0);
    etapa=8;
  }
  if((etapa==12)&&((dato_7==1)||(dato_7==3))){
    beep_Act=1;
  }
  if((etapa==15)&&((dato_7==2)||(dato_7==3))){
    beep_Act=1;
  }
  stepper.run(); // funcion de motor
 
}
